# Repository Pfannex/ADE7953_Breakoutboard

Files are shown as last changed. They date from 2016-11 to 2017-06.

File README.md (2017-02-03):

# ADE7953 MQTT Wattmeter

Der ADE7953 wird über einen ESP8266-WLAN-Controller per I²C angesteuert.
Aktuell gibt es nur ein Breakoutboard mit Grundbeschaltung. 
Die Ankopplung der Leistungsmessgrößen erfolgt zu einem späteren Zeitpunkt.

***

- **ADE7953**
  - [Kalibrierung](https://github.com/Pfannex/ADE7953_Breakoutboard/wiki/Kalibrierung-%7C-ADE7953-MQTT-Wattmeter)
- **Firmware**
  - [ESP8266-Web-Interface](https://github.com/Pfannex/ADE7953_Breakoutboard/wiki/ESP8266-Web-Interface-%7C-ADE7953-MQTT-Wattmeter)
  - [MQTT](https://github.com/Pfannex/ADE7953_Breakoutboard/wiki/MQTT-%7C-ADE7953-MQTT-Wattmeter)
  - [FileSystem](https://github.com/Pfannex/ADE7953_Breakoutboard/wiki/FileSystem-%7C-ADE7953-MQTT-Wattmeter)
  - [OTA](https://github.com/Pfannex/ADE7953_Breakoutboard/wiki/OTA-%7C-ADE7953-MQTT-Wattmeter)
- **FHEM**
  - [FHEM](https://github.com/Pfannex/ADE7953_Breakoutboard/wiki/FHEM-%7C-ADE7953-MQTT-Wattmeter)  
  
***
[ToDo](https://github.com/Pfannex/ADE7953_Breakoutboard/blob/master/ToDo.md)  
[changeLOG](https://github.com/Pfannex/ADE7953_Breakoutboard/blob/master/changeLOG.md)

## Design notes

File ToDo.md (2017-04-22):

#ToDo
Stand: 05.03.2017 / 16:43h  
letzte Änderung: Pf@nne

- **Hardware**
  - ~~CT-Test~~ - 20.01.2017
  - ~~Ankopplung 230VAC~~ - 05.03.2017
  
- **Firmware**
  - ~~MQTT max.150 Samples? jsonBuffer?~~ - 03.02.2017 - 1000 Samples @7kHz
  - ~~Begrenzung der SampleRate und der maximalen Samples~~ - 05.02.2017
  - mehrere Samples in einem 256Byte Frame pushen  --> das tut er doch schon?
  - ~~Topic resetEnergy REG, Value~~ 05.02.2017
  - ~~Topic /getValues/IA_INST Samples, kHz~~ - 05.02.2017 in SoftRegister implementiert
  - ~~Frequenz SoftRegister für GAIN~~ - 05.02.2017 SoftRegister PERIODGAIN hinzugefügt (223.75 + (read(PERIODGAIN)/1000)) obwohl die Korrektur Datasheet 223kHz -> 223.75kHz (3.58 MHz/16= 223.750 kHz clock) schon reichen würde
  - Kalibrierungsfunktion in FW implementieren
  - ~~WiKi Kalibrierungshinweis GAIN = 0x400000~~ - 30.01.2017
  - NTP wird viel zu häufig abgefragt - beim Start und jede Stunde einmal genügt
  - ~~Topic getWave hinzufügen alle drei Waves werden gestaffelt published~~ - 02.02.2017
  - ~~Sinnvolle Default-Werte für Samples und Periods mit setDefault setzen~~ wird im SoftRegister gesetzt
  - ~~ESP8266/Control/Relay publish/subscribe~~ - 15.02.17 Rückmeldestruktur in FHEM geht auch!
  - SoftClock, die vom NTP Client nur alle Stunde aktualisiert wird; NTP Server konfigurierbar machen
  - ~~getState implementieren~~ 23.02.17 
  - Button über Interrupt realisieren // ggf. nicht nötig
  - Webfrontend: verstecken der Kennwörter
  - Webfrontend: HTTPS, damit das WLAN-Kennwort nicht im Klartext übertragen wird (AP Mode und Client Mode)
  - Webfrontend: optisch aufpeppen
  - Webfrontend: javascript-Konsole
  - eine sinnvolle Verwendung für den GodMode finden

- **FHEM**
  - ~~Skalierung Plott in V/A nicht mV/mA~~ 30.01.2017 - FW fehler
  - Hüsch machen... :-)  z.B. ReadingsGroups
  - ToggleButton für die Umschaltung der MQTT-UpdateTime. "Normal" 60 Sekunden oder mehr. "Betrachten" 1 Sekunde
  - ~~ermöglichen, auch Samples im Format t1,x1;t2,x2;... im logProxyFile2xyPlot zu verarbeiten~~ 11.02.2017
  - ~~getState des Relais nach einem FHEM-Start abfragen~~ 23.02.17
  
***
##Themen:
```diff
+ Pf@nne
- Boris
```
  
###NTP
```diff
- NTP wird viel zu häufig abgefragt - beim Start und jede Stunde einmal genügt
+ Die UpdateTime ist an die MQTT-Update-Time angekoppelt. Im "normalen" Betrieb werden die Messwerte 
+ vielleicht einmal pro Minute published, da fällt neben den zig MQTT-Paketen das NTP-Paket nicht 
+ ins Gewicht. Eine Änderung würde die Implementaion einer "SoftClock" nach sich ziehen. 
+ SoftClock wird implementiert!
```

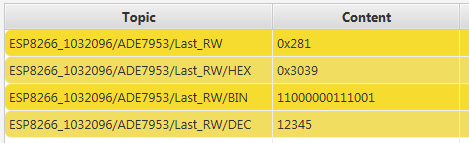
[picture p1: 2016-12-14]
Pics/write_return.PNG

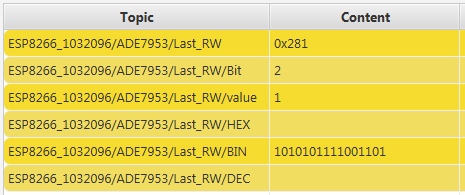
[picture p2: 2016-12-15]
Pics/readBit_return.PNG

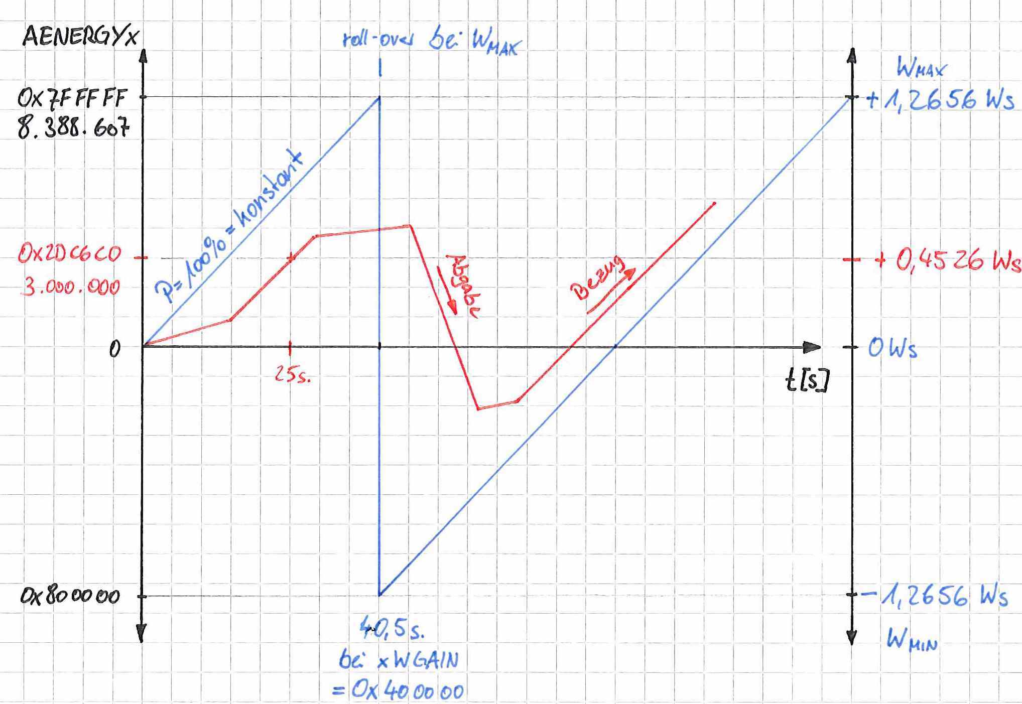
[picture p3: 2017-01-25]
Pics/Cal_Energy.jpeg

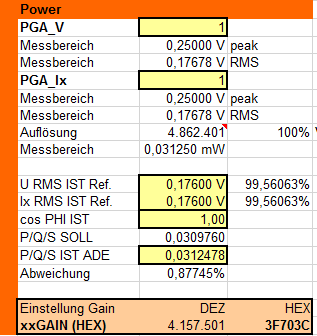
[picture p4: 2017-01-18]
Pics/Cal_Power.PNG

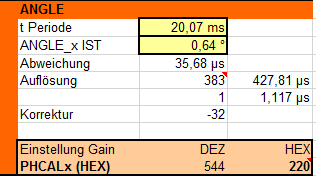
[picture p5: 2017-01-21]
Pics/Cal_Angle.PNG

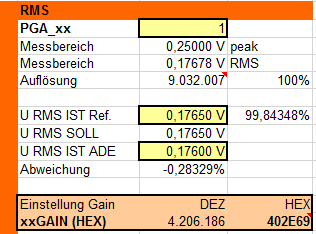
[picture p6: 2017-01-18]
Pics/Cal_RMS.PNG

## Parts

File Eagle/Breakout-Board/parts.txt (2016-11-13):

Partlist

Exported from ADE7953_WattMeter_breakout_v1.00.sch at 13.11.2016 07:56

EAGLE Version 7.7.0 Copyright (c) 1988-2016 CadSoft

Assembly variant: 

Part     Value               Device            Package    Library   Sheet

C1       .1uF                C-EUC0805K        C0805K@1   resistor  1
C2       4.7uF               CPOL-EUA/3216-18R A/3216-18R resistor  1
C3       .1uF                C-EUC0805K        C0805K@1   resistor  1
C4       4.7uF               CPOL-EUA/3216-18R A/3216-18R resistor  1
C5       10uF                CPOL-EUA/3216-18R A/3216-18R resistor  1
C6       .1uF                C-EUC0805K        C0805K@1   resistor  1
C7       18pF                C-EUC0805K        C0805K@1   resistor  1
C8       18pF                C-EUC0805K        C0805K@1   resistor  1
C9       .1uF                C-EUC0805K        C0805K@1   resistor  1
C10      4.7uF               CPOL-EUA/3216-18R A/3216-18R resistor  1
C11      1µF                 C-EUC0805K        C0805K@1   resistor  1
C12      33nF                C-EUC0805K        C0805K@1   resistor  1
C13      33nF                C-EUC0805K        C0805K@1   resistor  1
C14      33nF                C-EUC0805K        C0805K@1   resistor  1
C15      33nF                C-EUC0805K        C0805K@1   resistor  1
C16      33nF                C-EUC0805K        C0805K@1   resistor  1
C17      33nF                C-EUC0805K        C0805K@1   resistor  1
IC1      ADE7953ACPZLONGPADS ADE7953ACPZ5.0    VQFN-28-D  ade7953-2 1
JP1                          PINHD-1X14        1X14       pinhead   1
JP2                          PINHD-1X14        1X14       pinhead   1
JP3                          PINHD-1X2         1X02       pinhead   1
L1       445-2187-1-ND       L-EUL2012C        L2012C     resistor  1
Q1       535-10200-1-ND      CRYSTALSM49       SM49       crystal   1
R1       10k                 R-US_R0805        R0805@1    resistor  1
R2       300R                R-US_R0805        R0805@1    resistor  1
R3       300R                R-US_R0805        R0805@1    resistor  1
R4       10k                 R-US_R0805        R0805@1    resistor  1
R5       10k                 R-US_R0805        R0805@1    resistor  1
R6       1k                  R-US_R0805        R0805@1    resistor  1
R7       1k                  R-US_R0805        R0805@1    resistor  1
R8       1k                  R-US_R0805        R0805@1    resistor  1
R9       1k                  R-US_R0805        R0805@1    resistor  1
R10      1k                  R-US_R0805        R0805@1    resistor  1
R11      1k                  R-US_R0805        R0805@1    resistor  1
R12      10k                 R-US_R0805        R0805@1    resistor  1
R13      10k                 R-US_R0805        R0805@1    resistor  1
R14      10k                 R-US_R0805        R0805@1    resistor  1
R15      10k                 R-US_R0805        R0805@1    resistor  1
R16      10k                 R-US_R0805        R0805@1    resistor  1

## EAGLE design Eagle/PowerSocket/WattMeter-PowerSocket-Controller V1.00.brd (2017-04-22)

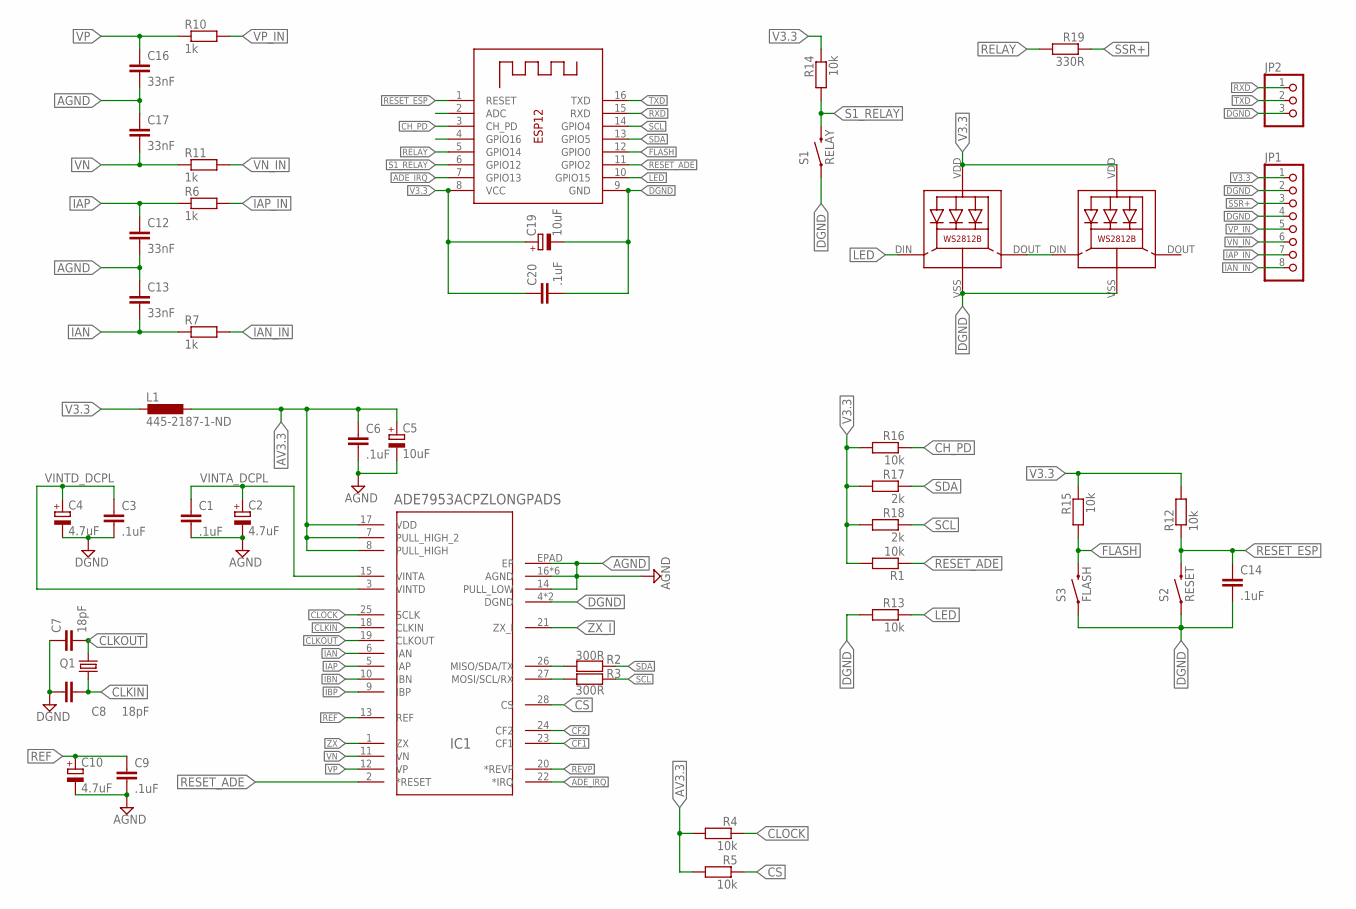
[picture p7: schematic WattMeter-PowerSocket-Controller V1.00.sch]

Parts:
C1, C3, C6, C9, C14, C20: .1uF; C0805K@1
C2, C4, C10: 4.7uF; A/3216-18R
C5, C19: 10uF; A/3216-18R
C7, C8: 18pF; C0805K@1
C12, C13, C16, C17: 33nF; C0805K@1
IC1: ADE7953ACPZLONGPADS; VQFN-28-D
JP1: PINHD-1X8; 1X08
JP2: PINHD-1X3; 1X03
L1: 445-2187-1-ND; L2012C
LED1, LED2: WS2812B
Q1: 535-10200-1-ND; SM49
R1, R4, R5, R12, R13, R14, R15, R16: 10k; R0805@1
R2, R3: 300R; R0805@1
R6, R7, R10, R11: 1k; R0805@1
R17, R18: 2k; R0805@1
R19: 330R; R0805@1
S1: RELAY; TACTILE-SWITCH-SMD
S2: RESET; TACTILE-SWITCH-1101NE
S3: FLASH; TACTILE-SWITCH-1101NE
X1: ESP-12

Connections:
ADC: X1.2 (ADC)
ADE_IRQ: IC1.22 (*IRQ), X1.7 (GPIO13)
AGND: C1.2, C2.-, C5.-, C6.2, C9.2, C10.-, C12.2, C13.1, C16.2, C17.1, IC1.14 (PULL_LOW), IC1.16 (AGND), IC1.29 (AGND), IC1.30 (AGND), IC1.31 (AGND), IC1.32 (AGND), IC1.EPAD (EP), IC1._AGND (AGND)
AV3.3: C5.+, C6.1, IC1.7 (PULL_HIGH_2), IC1.8 (PULL_HIGH), IC1.17 (VDD), L1.1, R4.2, R5.2
CF1: IC1.23 (CF1)
CF2: IC1.24 (CF2)
CH_PD: R16.1, X1.3 (CH_PD)
CLKIN: C8.2, IC1.18 (CLKIN), Q1.1
CLKOUT: C7.2, IC1.19 (CLKOUT), Q1.2
CLOCK: IC1.25 (SCLK), R4.1
CS: IC1.28 (CS), R5.1
DGND: C3.2, C4.-, C7.1, C8.1, C14.2, C19.-, C20.2, IC1.4 (DGND), IC1._DGND (DGND), JP1.2, JP1.4, JP2.3, LED1.VSS (GND), LED2.VSS (GND), R13.2, S1.1, S2.1, S3.1, X1.9 (GND)
FLASH: R15.2, S3.2, X1.12 (GPIO0)
GPIO16: X1.4 (GPIO16)
IAN: C13.2, IC1.6 (IAN), R7.1
IAN_IN: JP1.8, R7.2
IAP: C12.1, IC1.5 (IAP), R6.1
IAP_IN: JP1.7, R6.2
IBN: IC1.10 (IBN)
IBP: IC1.9 (IBP)
LED: LED1.DIN (DI), R13.1, X1.10 (GPIO15)
unnamed: LED1.DOUT (DO), LED2.DIN (DI)
REF: C9.1, C10.+, IC1.13 (REF)
RELAY: R19.2, X1.5 (GPIO14)
RESET_ADE: IC1.2 (*RESET), R1.1, X1.11 (GPIO2)
RESET_ESP: C14.1, R12.1, S2.2, X1.1 (RESET)
REVP: IC1.20 (*REVP)
RXD: JP2.1, X1.15 (RXD)
S1_RELAY: R14.2, S1.3 (2), X1.6 (GPIO12)
SCL: R3.2, R18.1, X1.14 (GPIO4)
SCL_: IC1.27 (MOSI/SCL/RX), R3.1
SDA: R2.2, R17.1, X1.13 (GPIO5)
SDA_: IC1.26 (MISO/SDA/TX), R2.1
SSR+: JP1.3, R19.1
TXD: JP2.2, X1.16 (TXD)
V3.3: C19.+, C20.1, JP1.1, L1.2, LED1.VDD, LED2.VDD, R1.2, R12.2, R14.1, R15.1, R16.2, R17.2, R18.2, X1.8 (VCC)
VINTA_DCPL: C1.1, C2.+, IC1.15 (VINTA)
VINTD_DCPL: C3.1, C4.+, IC1.3 (VINTD)
VN: C17.2, IC1.11 (VN), R11.1
VN_IN: JP1.6, R11.2
VP: C16.1, IC1.12 (VP), R10.1
VP_IN: JP1.5, R10.2
ZX: IC1.1 (ZX)
ZX_I: IC1.21 (ZX_I)

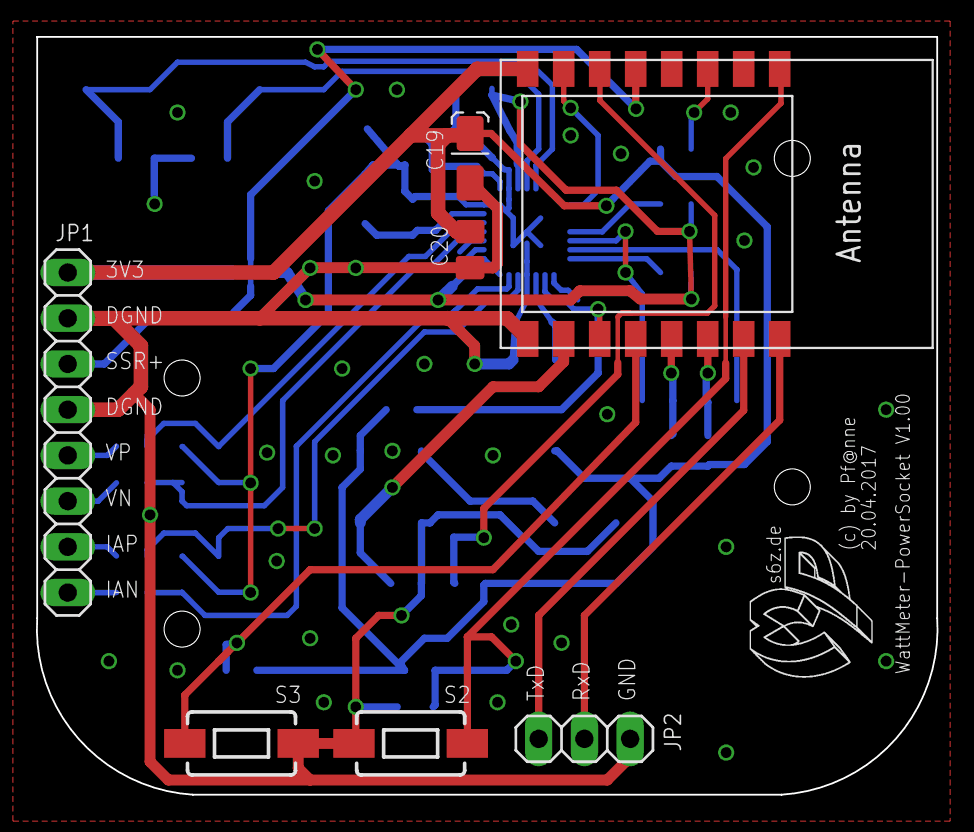
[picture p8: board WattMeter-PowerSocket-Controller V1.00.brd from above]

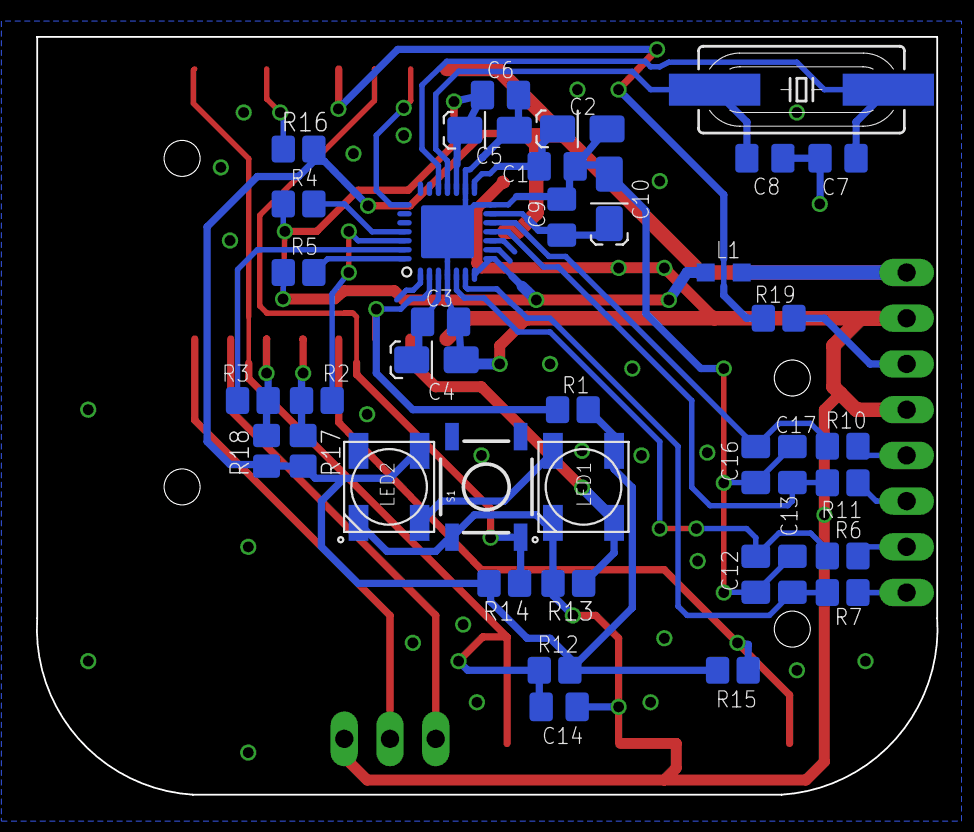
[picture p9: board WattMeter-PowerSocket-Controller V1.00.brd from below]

Board: 2 copper layers, 50.0 x 42.1 mm, 45 parts (38 on the bottom side), 35 nets.

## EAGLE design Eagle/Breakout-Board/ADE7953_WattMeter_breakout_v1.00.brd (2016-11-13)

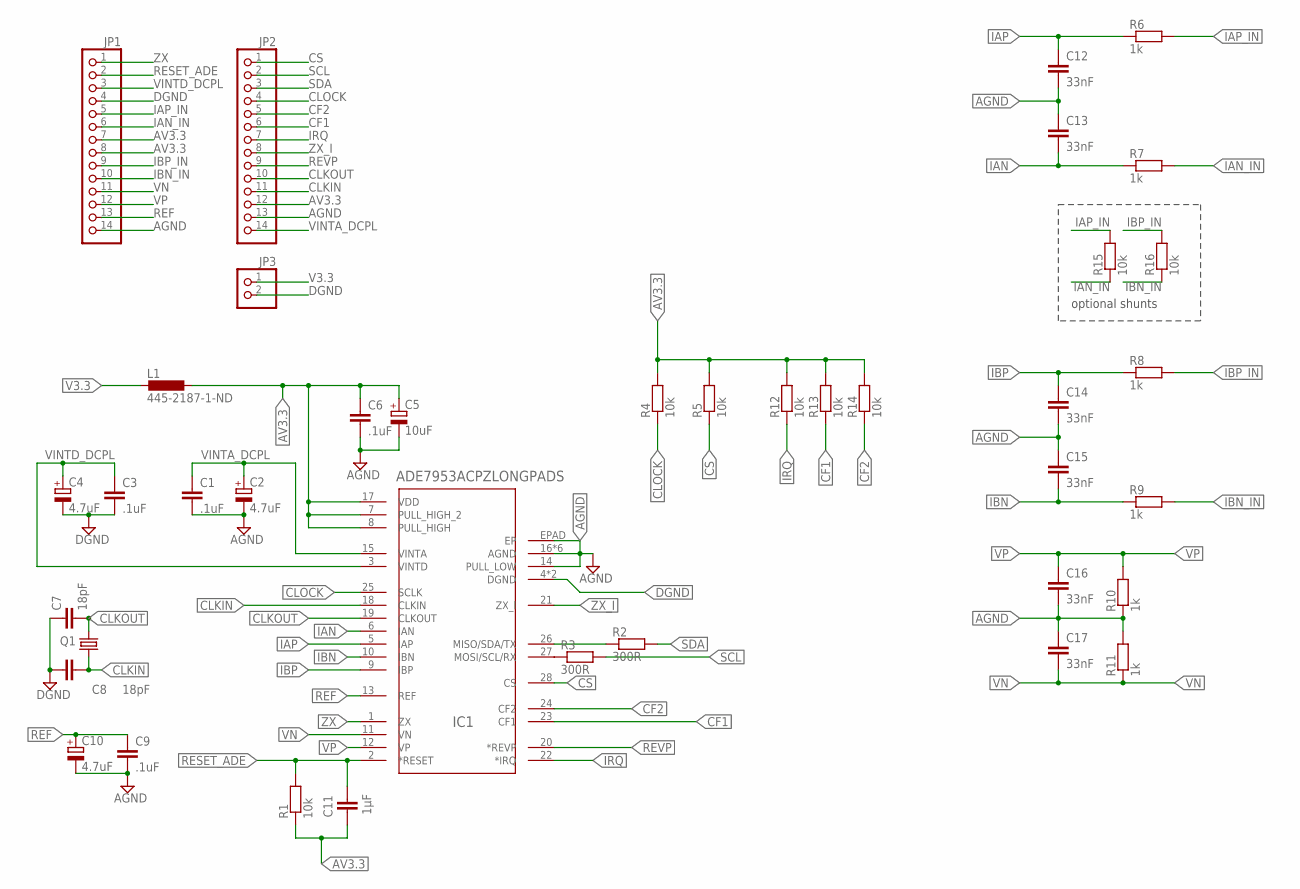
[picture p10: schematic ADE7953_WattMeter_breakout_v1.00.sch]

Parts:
C1, C3, C6, C9: .1uF; C0805K@1
C2, C4, C10: 4.7uF; A/3216-18R
C5: 10uF; A/3216-18R
C7, C8: 18pF; C0805K@1
C11: 1µF; C0805K@1
C12, C13, C14, C15, C16, C17: 33nF; C0805K@1
IC1: ADE7953ACPZLONGPADS; VQFN-28-D
JP1, JP2: PINHD-1X14; 1X14
JP3: PINHD-1X2; 1X02
L1: 445-2187-1-ND; L2012C
Q1: 535-10200-1-ND; SM49
R1, R4, R5, R12, R13, R14, R15, R16: 10k; R0805@1
R2, R3: 300R; R0805@1
R6, R7, R8, R9, R10, R11: 1k; R0805@1

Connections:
AGND: C1.2, C2.-, C5.-, C6.2, C9.2, C10.-, C12.2, C13.1, C14.2, C15.1, C16.2, C17.1, IC1.14 (PULL_LOW), IC1.16 (AGND), IC1.29 (AGND), IC1.30 (AGND), IC1.31 (AGND), IC1.32 (AGND), IC1.EPAD (EP), IC1._AGND (AGND), JP1.14, JP2.13, R10.1, R11.2
AV3.3: C5.+, C6.1, C11.2, IC1.7 (PULL_HIGH_2), IC1.8 (PULL_HIGH), IC1.17 (VDD), JP1.7, JP1.8, JP2.12, L1.1, R1.1, R4.2, R5.2, R12.2, R13.2, R14.2
CF1: IC1.23 (CF1), JP2.6, R13.1
CF2: IC1.24 (CF2), JP2.5, R14.1
CLKIN: C8.2, IC1.18 (CLKIN), JP2.11, Q1.1
CLKOUT: C7.2, IC1.19 (CLKOUT), JP2.10, Q1.2
CLOCK: IC1.25 (SCLK), JP2.4, R4.1
CS: IC1.28 (CS), JP2.1, R5.1
DGND: C3.2, C4.-, C7.1, C8.1, IC1.4 (DGND), IC1._DGND (DGND), JP1.4, JP3.2
IAN: C13.2, IC1.6 (IAN), R7.1
IAN_IN: JP1.6, R7.2, R15.1
IAP: C12.1, IC1.5 (IAP), R6.1
IAP_IN: JP1.5, R6.2, R15.2
IBN: C15.2, IC1.10 (IBN), R9.1
IBN_IN: JP1.10, R9.2, R16.1
IBP: C14.1, IC1.9 (IBP), R8.1
IBP_IN: JP1.9, R8.2, R16.2
IRQ: IC1.22 (*IRQ), JP2.7, R12.1
PIN26_MISO_SDA_TX: IC1.26 (MISO/SDA/TX), R2.1
PIN27_MOSI_SCL_RX: IC1.27 (MOSI/SCL/RX), R3.1
REF: C9.1, C10.+, IC1.13 (REF), JP1.13
RESET_ADE: C11.1, IC1.2 (*RESET), JP1.2, R1.2
REVP: IC1.20 (*REVP), JP2.9
SCL: JP2.2, R3.2
SDA: JP2.3, R2.2
V3.3: JP3.1, L1.2
VINTA_DCPL: C1.1, C2.+, IC1.15 (VINTA), JP2.14
VINTD_DCPL: C3.1, C4.+, IC1.3 (VINTD), JP1.3
VN: C17.2, IC1.11 (VN), JP1.11, R11.1
VP: C16.1, IC1.12 (VP), JP1.12, R10.2
ZX: IC1.1 (ZX), JP1.1
ZX_I: IC1.21 (ZX_I), JP2.8

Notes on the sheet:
optional shunts

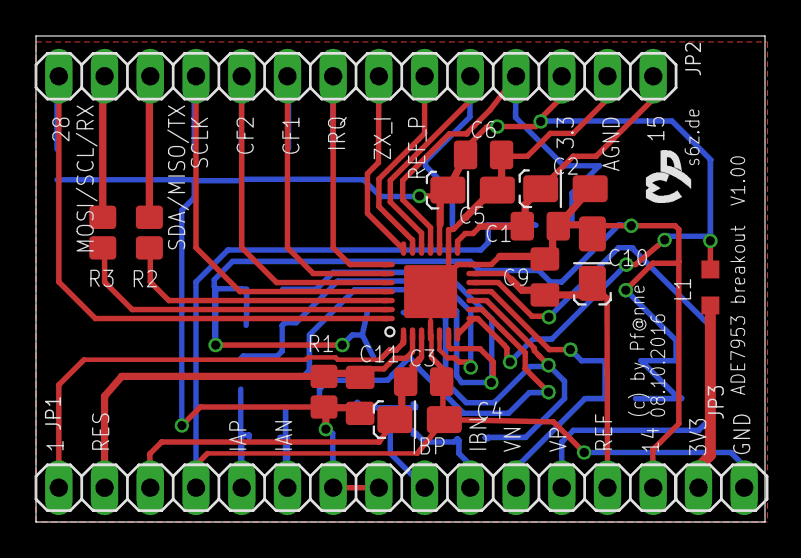
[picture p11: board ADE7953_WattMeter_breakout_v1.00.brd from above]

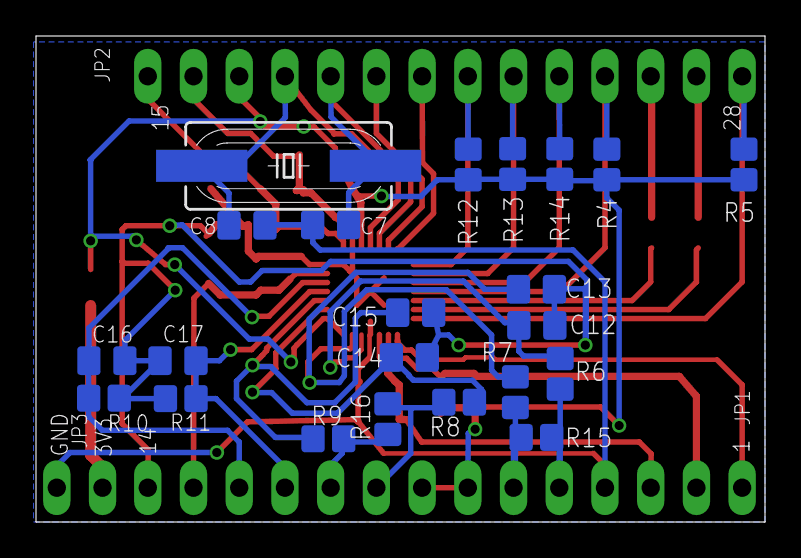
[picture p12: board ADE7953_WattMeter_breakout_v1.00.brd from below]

Board: 2 copper layers, 40.5 x 27.0 mm, 39 parts (22 on the bottom side), 32 nets.

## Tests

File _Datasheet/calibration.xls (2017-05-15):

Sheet: calc
RMS |  |  |  |  | xxGAIN | k_x
PGA_xx | 1 |  |  | V | 4134304
Messbereich | 0.25000 V | peak |  | IA | 4058342
Messbereich | 0.17678 V | RMS
Auflösung | 9032007 | 100%
U RMS IST Ref. | 0.10000 V | 56.56854% |  | Implementieung der Kalibrierung im ESP!
U RMS SOLL | 0.10000 V |  |  | Referenzmesswert eingeben ---> GAIN schreiben
U RMS IST ADE | 0.10348 V
Abweichung | 3.48000%
Einstellung Gain | DEZ | HEX
xxGAIN (HEX) | 4048342.221 | 3DC5D6
ANGLE
t Periode | 20.06 ms
ANGLE_x IST | 0.64 °
Abweichung | 35.66 µs
Auflösung | 383 | 427.81 µs
 | 1 | 1.117 µs
Korrektur | -31.92678802
Einstellung Gain | DEZ | HEX
PHCALx (HEX) | 543.926788 | 220
Power
PGA_V | 1
Messbereich | 0.25000 V | peak
Messbereich | 0.17678 V | RMS
PGA_Ix | 1
Messbereich | 0.25000 V | peak
Messbereich | 0.17678 V | RMS
Auflösung | 4862401 | 100% | V * Ix
Messbereich | 0.031250 W | 100%
U RMS IST Ref. | 0.17675 V | 99.98490%
Ix RMS IST Ref. | 0.17675 V | 99.98490%
cos PHI IST | 1.00
P/Q/S SOLL | 0.0312406
P/Q/S IST ADE | 0.0310917
Abweichung | -0.47650%
Einstellung Gain | DEZ | HEX
xxGAIN (HEX) | 4214290.022 | 404E13
Energy
 | DEZ | HEX
xWGAIN (HEX) | 4199134 | 4012de | default
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

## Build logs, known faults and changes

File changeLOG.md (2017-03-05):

#changeLOG
Stand: 05.03.2017 / 16:43h
letzte Änderung: Pf@nne

- **Hardware**
  - 
  
- **Firmware**
  - Topic /getWave hinzugefügt, V_INST, IA_INST und IB_INST werden nacheinader published
  - SoftRegister Period und SampleRate zur Steuerung der INST-Werte hinzugefügt
  - INST-Routinen überarbeitet, 1000 Samples mit 7kHz möglich
  - INST mit max 4kHz, Samples auf max. 500 begrenzt
  - INST nach dem publish der INST-Values erfolgt ein INSTready publish zum Refresh des SVG-Plots
  - Energy /resetEnergy mit Vorgabewert
  - SoftRegister PERIODGAIN hinzugefügt (223.75 + (read(PERIODGAIN)/1000)) obwohl die Korrektur Datasheet 223kHz -> 223.75kHz (3.58 MHz/16= 223.750 kHz clock) schon reichen würde
  - Ansteuerung des Relais über MQTT
  - MQTT LastWill, QoS und retain hinzugefügt
  - getState liefert den aktuellen Status des RelaisOutputs
  - MQTT subcribe bereinigt, kein FeedbackLoop mehr
  - getWave wird erst ab 1% Spannungsmesswert angestoßen (endlos while, wait for ZeroCross)
  - NTP.timeUpdate vorläufig entfernt

- **FHEM**
  - dummys für INST-Werte ergänzt
  - Pfanne_fhem.cfg abgelegt
  - INST funktionalitäten erweitert
  - INST-Samples in Frames möglich [tt,vv;tt,vv;-tt,-vv]
  - Ansteuerung des Relais mit Rückmeldestruktur
  - ESP8266 StatusWatcher hinzugefügt
  - Nach dem FHEM-Start wir der aktuelle RelaisState automatisch geholt

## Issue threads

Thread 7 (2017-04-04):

Copyright/Duplicating

Godsendviii, 2017-04-04:
Hi Pfannex,

Thank you for creating this repository for the ade7953. We are also using esp8266 for our system.
It would be a huge help if we can use this breakout board to learn how to use the chip. In that case, with your permission, would you grant us the right to duplicate this breakout board?

Best,
Godsendviii

Pfannex, 2017-04-04:
Moin Godsendviii,

is this for private or commercial use?

Godsendviii, 2017-04-04:
For private use, we want to learn how to use it.

Pfannex, 2017-04-06:
Hi,
for non commercial use you can fork the repository, have fun with this stuff.
If you want you can get some Breakout-Boards.

Please send me a message to pf@nne-mail.de...

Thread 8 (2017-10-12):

VP /VN

xD150, 2017-10-12:
Moin Moin,
schöne Grüße aus dem Norden.
Erstmal ein großes Lob an deine Arbeit.
Da ich momentan auch mit dem ESP arbeite, wollte ich dein Projekt bei mir in der Wohnung integrieren.
Nun habe eine Frage bezüglich des VP_IN /VN_IN, legst du dort direkt L1 / N an oder Transformierst du es vorher noch runter? Dort ist ja bis jetzt keine Galvanische Trennung vorhanden oder stehe ich dort auf dem Schlauch?

Gruß
Torben

Pfannex, 2017-10-12:
Moin Torben,

danke für das Lob!

>Nun habe eine Frage bezüglich des VP_IN /VN_IN, legst du dort direkt L1 / N an oder Transformierst du es vorher noch runter?

Bist du sicher, dass du sicher mit 230VAC umgehen kannst?

Bist du vom Fach?

Eine galvanische Trennung ist ebenso notwendig wie die Anpassung auf Kleinsignalstärke.

Der ADE kann an den Eingängen maximal 500mV (250mV) vertragen.

Ich nutze dafür diese Stromwandler
https://de.aliexpress.com/item/YHDC-TV16-250V-2mA-PCB-mount-Voltage-transformer/32295086502.html?

Gruß

Marco

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

xD150, 2017-10-13:
danke für die schnelle Antwort, ja ich bin selbst ausgebildeter Elektroniker für Geräte und Systeme.
Meine Frage war ein wenig doof gestellt, dass es auf Kleinsignal muss war mir bewusst. Ich habe bei bloß den ADE auch schon gesehen, dass dort keine Galvanische Trennung stattfindet und die direkt über 1M und 1k Skaliert wird, weil dort dann keine Phasenverschiebung des Transformators entsteht und man sich somit die Kalibrierung der Phase erspart.

Gruß
Torben

Pfannex, 2017-10-13:
Moin Torben,
OK, dann bin ich ja beruhigt....Hatte mir schon Sorgen gemacht....
Es geht natürlich auch ohne galvanische Trennung, ich würde aber den Stromwandler empfehlen.Die laufen echt stabil.....Die Kalibrierung der Phasenlage ist kein Problem, du musst ja auch den Strom noch irgendwie umsetzen.
MfGPf@nne

-------- Ursprüngliche Nachricht --------
Von: xD150 <notifications@github.com>
Datum: 13.10.17  10:21  (GMT+01:00)
An: Pfannex/ADE7953_Breakoutboard <ADE7953_Breakoutboard@noreply.github.com>
Cc: "Pf@nne" <pf@nne-mail.de>, Comment <comment@noreply.github.com>
Betreff: Re: [Pfannex/ADE7953_Breakoutboard] VP /VN (#8)

danke für die schnelle Antwort, ja ich bin selbst ausgebildeter Elektroniker für Geräte und Systeme.

Meine Frage war ein wenig doof gestellt, dass es auf Kleinsignal muss war mir bewusst. Ich habe bei bloß den ADE auch schon gesehen, dass dort keine Galvanische Trennung stattfindet und die direkt über 1M und 1k Skaliert wird, weil dort dann keine Phasenverschiebung des Transformators entsteht und man sich somit die Kalibrierung der Phase erspart.
Gruß

Torben

—
You are receiving this because you commented.
Reply to this email directly, view it on GitHub, or mute the thread.

{"api_version":"1.0","publisher":{"api_key":"05dde50f1d1a384dd78767c55493e4bb","name":"GitHub"},"entity":{"external_key":"github/Pfannex/ADE7953_Breakoutboard","title":"Pfannex/ADE7953_Breakoutboard","subtitle":"GitHub repository","main_image_url":"https://cloud.githubusercontent.com/assets/143418/17495839/a5054eac-5d88-11e6-95fc-7290892c7bb5.png","avatar_image_url":"https://cloud.githubusercontent.com/assets/143418/15842166/7c72db34-2c0b-11e6-9aed-b52498112777.png","action":{"name":"Open in GitHub","url":"https://github.com/Pfannex/ADE7953_Breakoutboard"}},"updates":{"snippets":[{"icon":"PERSON","message":"@xD150 in #8: danke für die schnelle Antwort, ja ich bin selbst ausgebildeter Elektroniker für Geräte und Systeme.\r\nMeine Frage war ein wenig doof gestellt, dass es auf Kleinsignal muss war mir bewusst. Ich habe bei bloß den ADE auch schon gesehen, dass dort keine Galvanische Trennung stattfindet und die direkt über 1M und 1k Skaliert wird, weil dort dann keine Phasenverschiebung des Transformators entsteht und man sich somit die Kalibrierung der Phase erspart. \r\n\r\nGruß\r\nTorben"}],"action":{"name":"View Issue","url":"https://github.com/Pfannex/ADE7953_Breakoutboard/issues/8#issuecomment-336384613"}}}

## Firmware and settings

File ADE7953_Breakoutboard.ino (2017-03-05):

/******************************************************************************

  ProjectName: ADE7953-Test Sketch                ***** *****
  SubTitle   : ADE7953-WattMeter                 *     *     ************
                                                *   **   **   *           *
  Copyright by Pf@nne                          *   *   *   *   *   ****    *
                                               *   *       *   *   *   *   *
  Last modification by:                        *   *       *   *   ****    *
  - Pf@nne (pf@nne-mail.de)                     *   *     *****           *
                                                 *   *        *   *******
  Date    : 03.12.2016                            *****      *   *
  Version : alpha 0.200                                     *   *
  Revison :                                                *****

********************************************************************************/

#include "ESP8266_Basic.h"
ESP8266_Basic espClient;

  //int dcount= 0;

void tick(void *pArg) {
  espClient.timerCallback();
}


void setup() {  
  Serial.begin(115200); 
  Serial.println("");

  espClient.setup_Timer();
  espClient.setup_Peripherals();
  espClient.start_WiFi_connections();
  espClient.run_I2C();
  espClient.ADE.init();
  //espClient.ADE.Test();


} 

//void d(char *p) {
  //Serial.print(p);
  //if(!(dcount++ % 50)) Serial.println(); }
 

void loop() {
  //d("C");
  espClient.handle_connections();
  //d("M");
  espClient.handle_Measurement();
  //d("P");
  espClient.handle_Peripherals();

/*  espClient.handle_connections(); 
  espClient.handle_Measurement();
  espClient.handle_Peripherals();*/
}

/*ToDo
 * readBit / writeBit by Name
 * DONE -  write only changed json, at MQTT command 
 * DONE - SAVE
 * LastRW aus Register
 * Topics auf json
 * DONE Reading int/uint
 * DONE element reading
 * FS Abfrage ob Feld vorhanden, sonst ggf. format
 * write register from MQTT by Name
 * k-Faktor
 */

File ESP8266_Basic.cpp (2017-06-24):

/******************************************************************************

  ProjectName: ESP8266 Basic template             ***** *****
  SubTitle   : Basic routines                    *     *     ************
                                                *   **   **   *           *
  Copyright by Pf@nne                          *   *   *   *   *   ****    *
                                               *   *       *   *   *   *   *
  Last modification by:                        *   *       *   *   ****    *
  - Pf@nne (pf@nne-mail.de)                     *   *     *****           *
                                                 *   *        *   *******
  Date    : 03.12.2016                            *****      *   *
  Version : alpha 0.200                                     *   *
  Revison :                                                *****

********************************************************************************/
#include "ESP8266_Basic.h"

//===> variables <---------------------------------------------------------

//BMP180 Luftdruck
  //Adafruit_BMP085 bmp;

//CLASS ESP8266_Basic################################################################
ESP8266_Basic::ESP8266_Basic() : webServer(), 
                                 mqtt_client(wifi_client),
                                 timeClient(ntpUDP, "europe.pool.ntp.org", 3600,1000){
                                 // By default 'time.nist.gov' is used with 60 seconds update interval and
                                 // no offset
                                 // You can specify the time server pool and the offset, (in seconds)
                                 // additionaly you can specify the update interval (in milliseconds).
                                 // NTPClient timeClient(ntpUDP, "europe.pool.ntp.org", 3600, 60000);

  //Callbacks								 
  //ADE.set_Callback(std::bind(&ESP8266_Basic::adeCallback, this));  
  ADE.setADECallback(std::bind(&ESP8266_Basic::ade_Callback, this, std::placeholders::_1, std::placeholders::_2));
  
  webServer.set_saveConfig_Callback(std::bind(&ESP8266_Basic::cfgChange_Callback, this));
  mqtt_client.setCallback(std::bind(&ESP8266_Basic::mqttBroker_Callback, this, std::placeholders::_1, std::placeholders::_2, std::placeholders::_3));
}
//===> ADE Callback <---------------------------------------------------
//void ESP8266_Basic::adeCallback(){
  //Serial.print("ADE Callback -> "); Serial.println("xx");
 
//}



//===============================================================================
//  incomming subscribe 
//===============================================================================
//===> incomming subscribe <---------------------------------------------------
void ESP8266_Basic::mqttBroker_Callback(char* topic, byte* payload, unsigned int length) {

  char value[500] = "";
  char chr[500] = "";
  int samples = 50;
  double inst[samples];
  String str = "";
  String attr[10];

  int attrCount = 0;  
  for (int i = 0; i < length; i++) {
    value[i] = payload[i];
    char x = payload[i];
    String y = String(x);
    if (y == "," ){
      attrCount++;     
    }else{
      attr[attrCount] += (char)payload[i];
    }
  }

  TdissectResult dissectResult;    
  dissectResult = dissectPayload(topic, value);
  
  Serial.println("##incoming subscribe##########");
  //Serial.print("incoming subscribe - LEN: ");
  //Serial.print(length);
  //Serial.print(" | ");
  Serial.println(topic);
  //Serial.print(" | ");
  Serial.println(value);
  Serial.println("");
  //Serial.print("path: ");Serial.println(dissectResult.itemPath);*/

  if (dissectResult.found){
    
//201 ADE7953.read
    if (dissectResult.itemPath == "2/0/1"){
      String strReg = "0x";
      strReg += String(ADE.StrToInt(value), HEX);
      strcpy(chr, strReg.c_str());
      pub(2,0, chr);
      String str = ADE.getRegName(ADE.StrToInt(value));      
      strcpy(chr, str.c_str());
      pub(2,0,5, chr);
      
      uint32_t reg = ADE.read(String(value));
      str = "0x";
      str += String(reg, HEX);
      strcpy(chr, str.c_str());
      pub(2,0,0, chr);
      str = String(reg, BIN);
      strcpy(chr, str.c_str());
      pub(2,0,1, chr);
      str = String(reg);
      strcpy(chr, str.c_str());
      pub(2,0,2, chr);
    }
    
//202 ADE7953.write
    if (dissectResult.itemPath == "2/0/2"){   
      //Serial.println("Write to ADE");
            
      ADE.write(String(value));
      
      String strReg = "0x";
      int pos = String(value).indexOf(",");
      strReg += String(ADE.StrToInt(String(value).substring(0, pos)), HEX);
      
      strcpy(chr, strReg.c_str());
      pub(2,0, chr);
      String str = ADE.getRegName(ADE.StrToInt(value));      
      strcpy(chr, str.c_str());
      pub(2,0,5, chr);

      
      uint32_t reg = ADE.read(String(value));      
      str = "0x";
      str += String(reg, HEX);
      strcpy(chr, str.c_str());
      pub(2,0,0, chr);
      str = String(reg, BIN);
      strcpy(chr, str.c_str());
      pub(2,0,1, chr);
      str = String(reg);
      strcpy(chr, str.c_str());
      pub(2,0,2, chr);
    }

//203 ADE7953.readBit
    if (dissectResult.itemPath == "2/0/3"){               
      bool val = ADE.readBit(String(value));

      String strReg = "0x";
      int pos = String(value).indexOf(",");
      strReg += String(ADE.StrToInt(String(value).substring(0, pos)), HEX);
      strcpy(chr, strReg.c_str());
      pub(2,0, chr);
      String str = ADE.getRegName(ADE.StrToInt(value));      
      strcpy(chr, str.c_str());
      pub(2,0,5, chr);

      strReg = String(value).substring(pos+1);
      strcpy(chr, strReg.c_str());
      pub(2,0,3, chr);
      
      strReg = String(val);
      strcpy(chr, strReg.c_str());
      pub(2,0,4, chr);

      pub(2,0,0, "");
      
      uint32_t reg = ADE.read(ADE.StrToInt(String(value)));
      str = "0b";
      str = String(reg, BIN);
      strcpy(chr, str.c_str());     
      pub(2,0,1, chr);
      
      pub(2,0,2, "");
    }
    
//204 ADE7953.writeBit
    if (dissectResult.itemPath == "2/0/4"){   
      ADE.writeBit(String(value));

      String strReg = "0x";
      int pos = String(value).indexOf(",");
      strReg += String(ADE.StrToInt(String(value).substring(0, pos)), HEX);
      strcpy(chr, strReg.c_str());
      pub(2,0, chr);
      String str = ADE.getRegName(ADE.StrToInt(value));      
      strcpy(chr, str.c_str());
      pub(2,0,5, chr);

      uint32_t reg = ADE.read(ADE.StrToInt(strReg));
      str = "0x";
      str += String(reg, HEX);
      strcpy(chr, str.c_str());
      pub(2,0,0, chr);
      str = String(reg, BIN);
      strcpy(chr, str.c_str());
      pub(2,0,1, chr);
      str = String(reg);
      strcpy(chr, str.c_str());
      pub(2,0,2, chr);      
    }
    
//205 ADE7953.init
    if (dissectResult.itemPath == "2/0/5"){         
      ADE.init();
    }
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

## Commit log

2016-12-11 Revert "save"
    This reverts commit 7f53961af1482455b5bff8486c0d0f5bdfaa4c04.
    [ADE7953.cpp, ESP8266_Basic.cpp]
2017-01-14 Update Measurement
    [calibration.xls]
2017-01-15 update instantaneous measurement
    [calibration.xls]
2017-01-18 Update
    INST V,IA,IB.... OK
    P,Q,S power measurement.... OK
    Excel calibration sheet.... OK
    [calibration.xls]
2017-01-18 Upload Pics
    [calibration.xls]
2017-01-21 Update ANGLE calc
    [calibration.xls]
2017-01-21 add Energy measurement / at Work
    [calibration.xls]
2017-01-22 FHEM sample configuration added
2017-01-22 modify I2C
2017-01-23 I2C write not working
    [ADE7953.cpp]
2017-01-23 I2C r/w Test
2017-01-23 I2C read up to 800kHz
2017-01-25 Energy measurement working!
    [calibration.xls]
2017-02-01 getWaves 240 Samples@3kHz
2017-02-04 Relay added to peripherals, Blink mode added to LED
2017-02-04 more samples mor performance
2017-02-13 add MQTT relay control
2017-02-18 TEMP relay
2017-02-26 update - still problems
    [ADE7953.cpp, ESP8266_Basic.cpp]
2017-03-01 new upload
    [Pfanne_fhem.cfg, calibration.xls]
2017-03-19 Updated FHEM configuration file samples
2017-04-16 Update Eagle PowerSocket
    [ADE7953_WattMeter_breakout_v1.00.GBL, ADE7953_WattMeter_breakout_v1.00.GBO, ADE7953_WattMeter_breakout_v1.00.GBP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]
